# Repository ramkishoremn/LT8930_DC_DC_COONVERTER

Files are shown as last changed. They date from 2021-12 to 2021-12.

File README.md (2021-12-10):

# LT8930_DC_DC_COONVERTER
LT8390 - HIGH EFFICIENCY, SYNCHRONOUS BUCK-BOOST CONTROLLER
This design is based on a LT8390 and has a wider operating voltage range, 6 to 60V input and 1 to 60V output.

In addition, it also has an accurate Under-voltage Lockout with programmable hysteresis, perfect for powering from battery systems.

It also includes output current limiting and Spread Spectrum Frequency Modulation for Low EMI.

This board has been designed to fit into a Hammond 1455C802 Enclosure.

DESIGN CONSIDERATIONS
The LT8390 is a synchronous 4-switch buck-boost DC/DC controller that allows the output voltage to be above, below or equal to the input voltage.

Not only does this provide an extremely flexible DC-DC, it is also ideal for battery operated systems where the battery terminal voltage can fluctuate depending upon the state of charge (SoC). For example, I have been using this converter with a QNAP NAS (Network Attached Storage) to obtain a stable 12.0V (as it directly feeds the HDDs) from a 12V battery that could range anywhere from 10.8V to 14.4V.

The LT8390 operates in current mode and senses the current flowing through the inductor via the inductor sense resistor (R6).

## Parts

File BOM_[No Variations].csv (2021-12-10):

Quantity | Designator | Manufacturer Part Number | Comment | Description | Footprint | LibRef
6 | C1, C2, C3, C4, C5, C6 | EEEFK1J330P | 33uF | Cap Aluminum 33uF 63V 20% (8 X 10.2mm) SMD 250mA 2000h 105 C T/R | PCB-9g04u1co75526zy4kkrl-1 | CMP-7693bfcb6deba954-3
4 | C7, C8, C9, C10 | HMK325C7475MM-PE | 4.7uF | Cap , Midhigh Vol, 1210, 100v, X7s, 4.7uf20% , t&r | CAPC3225X229X50ML20T25 | CMP-cbb5062a85501472-2
2 | C11, C17 | 12101C105KAT2A | 1uF | CAP CER 1UF 100V 10% X7R 1210 | CAPC3225X279X50ML20T25 | CMP-127163-3
3 | C12, C13, C18 | 08055C104JAT2A | 100nF | Capacitor; Ceramic; Cap 0.1 uF; Tol 5%; Vol-Rtg 50 VDC; SMT; 0805; X7R; Tape & Reel | CAPC2013X140X50ML20T25 | CMP-54a29ee556ae8b65-2
1 | C14 | 0805ZD475KAT2A | 4.7uF | CAP CER 4.7UF 10V 10% X5R 0805 | CAPC2013X140X50ML20T25 | CMP-126761-3
1 | C15 | 08055C474JAT2A | 470nF | Multilayer Ceramic Capacitors MLCC - SMD/SMT .47uF 50v 20% Tol. | CAPC2013X140X50ML20T25 | CMP-3555014-4
1 | C16 | 08055C104JAT2A | DNF | Capacitor; Ceramic; Cap 0.1 uF; Tol 5%; Vol-Rtg 50 VDC; SMT; 0805; X7R; Tape & Reel | CAPC2013X140X50ML20T25 | CMP-54a29ee556ae8b65-2
1 | C19 | 08055C103JAT2A | 10nF | cap smd 0805 | CAPC2013X94X50ML20T25 | CMP-16466678-4
1 | D1 | LTST-C170KRKT | Lite-On LTST-C170KRKT | Red 2 x 1.25 x 1.1 mm 130° Water Clear 54 mcd 2 V LED Surface Mount | PCB-5ta9mte2am12bu12jwvi-1 | CMP-1544870-4
1 | F1 | 0154010.DR | 10A | 154 Series Fast-Acting 125 V 10 A OMNI-BLOK® Surface Mount Fuse & Holder | PCB-nlucop3bvobg45y57dd7-1 | CMP-254385-4
1 | J1 | 1757242 | Input | Phoenix 1757242 MSTBA 2.5/ 2-G-5.08 Base Strip/Header 4 Kilo-Volt Surge 320 Volt Rated III/2 12 Amp Green Plug-In | PCB-aknpg75yzj2hq04tmkjt-1 | CMP-0680cf8a1162d947-2
1 | J2 | 1757242 |  | Phoenix 1757242 MSTBA 2.5/ 2-G-5.08 Base Strip/Header 4 Kilo-Volt Surge 320 Volt Rated III/2 12 Amp Green Plug-In | PCB-aknpg75yzj2hq04tmkjt-1 | CMP-0680cf8a1162d947-2
1 | L1 | 7443631000 | 7443631000 | SMD High Current Inductor WE-HCF, L=10.0 µH | WE-HCF-2013 | CMP-913017-2
1 | LP1 | RLP1-200-500 | Bivar RLP1-200-500 | Single Station; 2.8mm; Enhanced Rigid Light Pipe; 5.0mm Elevation; 14.0mm Protrusion | PCB-yzipw91yj2ww1iciyfp2-1 | CMP-b0a0789a751f6f67-3
4 | Q1, Q2, Q3, Q4 | BSC027N06LS5ATMA1 | BSC027N06LS5 | N-Channel OptiMOS5 Power Transistor, 60V VDS, 100A ID, PG-TDSON-8-1 | INF-PG-TDSON-8-1_V | CMP-9dc451c8cc734203-2
1 | R1 | ERJ-MS4HF10MU | 0.01 | Res Metal Alloy 2512 10m Ohm 1% 2W ±75ppm/°C Molded SMD Embossed Carrier T/R | Resistor | CMP-3ffef57a43e1e039-1
1 | R2 | RC0805FR-07182KL | 182K | RES SMD 182K OHM 1% 1/8W 0805 | RESC2013X60X35ML10T20 | CMP-1854500-2
1 | R3 | RC0805FR-07221KL | 221K | Res Thick Film 0805 221K Ohm 1% 0.125W(1/8W) ±100ppm/C Epoxy Pad SMD T/R | RESC2013X60X35ML10T20 | CMP-3600ff19ac10e9c7-1
1 | R4 | RC0805FR-072K8L | 2K8 | RES SMD 2.8K OHM 1% 1/8W 0805 | RESC2013X60X35ML10T20 | CMP-1854595-2
1 | R5 | RC0805FR-0726K1L | 26K1 | Res Thick Film 2.0 x 1.2 mm 26.1K Ohm 1% 0.125W(1/8W) 100ppm/ C Molded SMD Paper T/R | PCB-krsl2knfs9oa082fmtmn-1 | CMP-ab5460010ab47493-2
1 | R6 | ERJ-MS4SF4M0U | 0.004 | Current sense resistor [Panasonic Automotive & Industrial Systems] ERJMS4SF4M0U Current sense resistor | Resistor | CMP-c31e099abffa1cd9-1
1 | R7 | 3296X-1-504LF | Bourns 3296X-1-504LF | Res Cermet Trimmer 500K Ohm 10% 1/2W 25(Elec)Turn 2.19mm (11.05 X 4.83 X 10.03mm) Pin Thru-Hole Tube | PCB-8uuv2uwn1geg2g5qqyha-1 | CMP-793ab03899fca6fd-3
1 | R8 | RC0805FR-0710KL | 10K | RC Series 0805 0.125 W 10 kOhms 1% ±100 ppm/°C SMT Thick Film Chip Resistor | RESC2013X60X35ML10T20 | CMP-1854303-12
3 | R9, R10, R12 | RC0805FR-070RL | 0 | Res Thick Film 0805 0 Ohm Molded SMD Paper T/R | RESC2013X60X35ML10T20 | CMP-1875921-8
1 | R11 | RC0805FR-07330RL | 330 | RC Series 0805 0.125 W 330 Ohms 1% ±100 ppm/°C SMT Thick Film Chip Resistor | RESC2013X60X35ML10T20 | CMP-e8e92397713d372e-2
1 | R13 | RC0805FR-072K2L | 2K2 | Res Thick Film 0805 2.2K Ohm 1% 0.125W(1/8W) 100ppm/ Molded SMD Paper T/R | RESC2013X60X35ML10T20 | CMP-18c6d3bcd80fc701-3
1 | R14 | RC0805FR-07100KL | 100K | Res Thick Film 0805 100K Ohm 1% 0.125W(1/8W} 100ppm/Molded SMD Paper T/R | RESC2013X60X35ML10T20 | CMP-1854318-18
1 | R15 | RC0805FR-070RL | DNF | Res Thick Film 0805 0 Ohm Molded SMD Paper T/R | RESC2013X60X35ML10T20 | CMP-1875921-8
1 | S1 | 200MSP1T2B2M7RE | SW-SPDT-3_B | 200 Series SPDT On-None-On Right Angle Sub-Miniature Toggle Switch | PCB-nfio538mx6iu86i8e1eg-1 | CMP-d175186fcc2b0eb2-2
1 | U1 | LT8390EUFD#PBF | LT8390EUFD#PBF | LT8390 - 60V Synchronous 4-Switch Buck-Boost Controller with Spread Spectrum | LT-UFD-28_M | CMP-ac1b61931e1b73dc-2

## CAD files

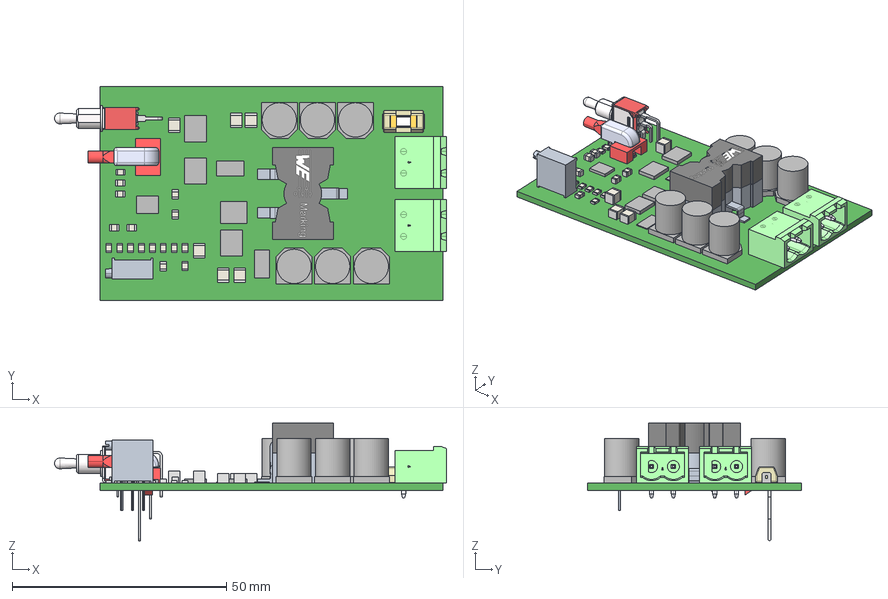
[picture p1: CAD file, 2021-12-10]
STEP_[No Variations].step
91.4 x 50.0 x 27.4 mm
Extruded x 90
Core_base_customer x 2
Core_customer
mstba_2.5-2-g-5.08 x 2
User_Library-OMNI-BLOK_littelfuse
3296X_(1)
200-400-800_MSP_BODY
200-400-800_MSP_BRACKET
200_B2
200_T2
200-400-800_MSP_M7
200-400-800_MSP-DP_M7_SUPPORT
LPR1-200-500-7
RLPH1-1-7

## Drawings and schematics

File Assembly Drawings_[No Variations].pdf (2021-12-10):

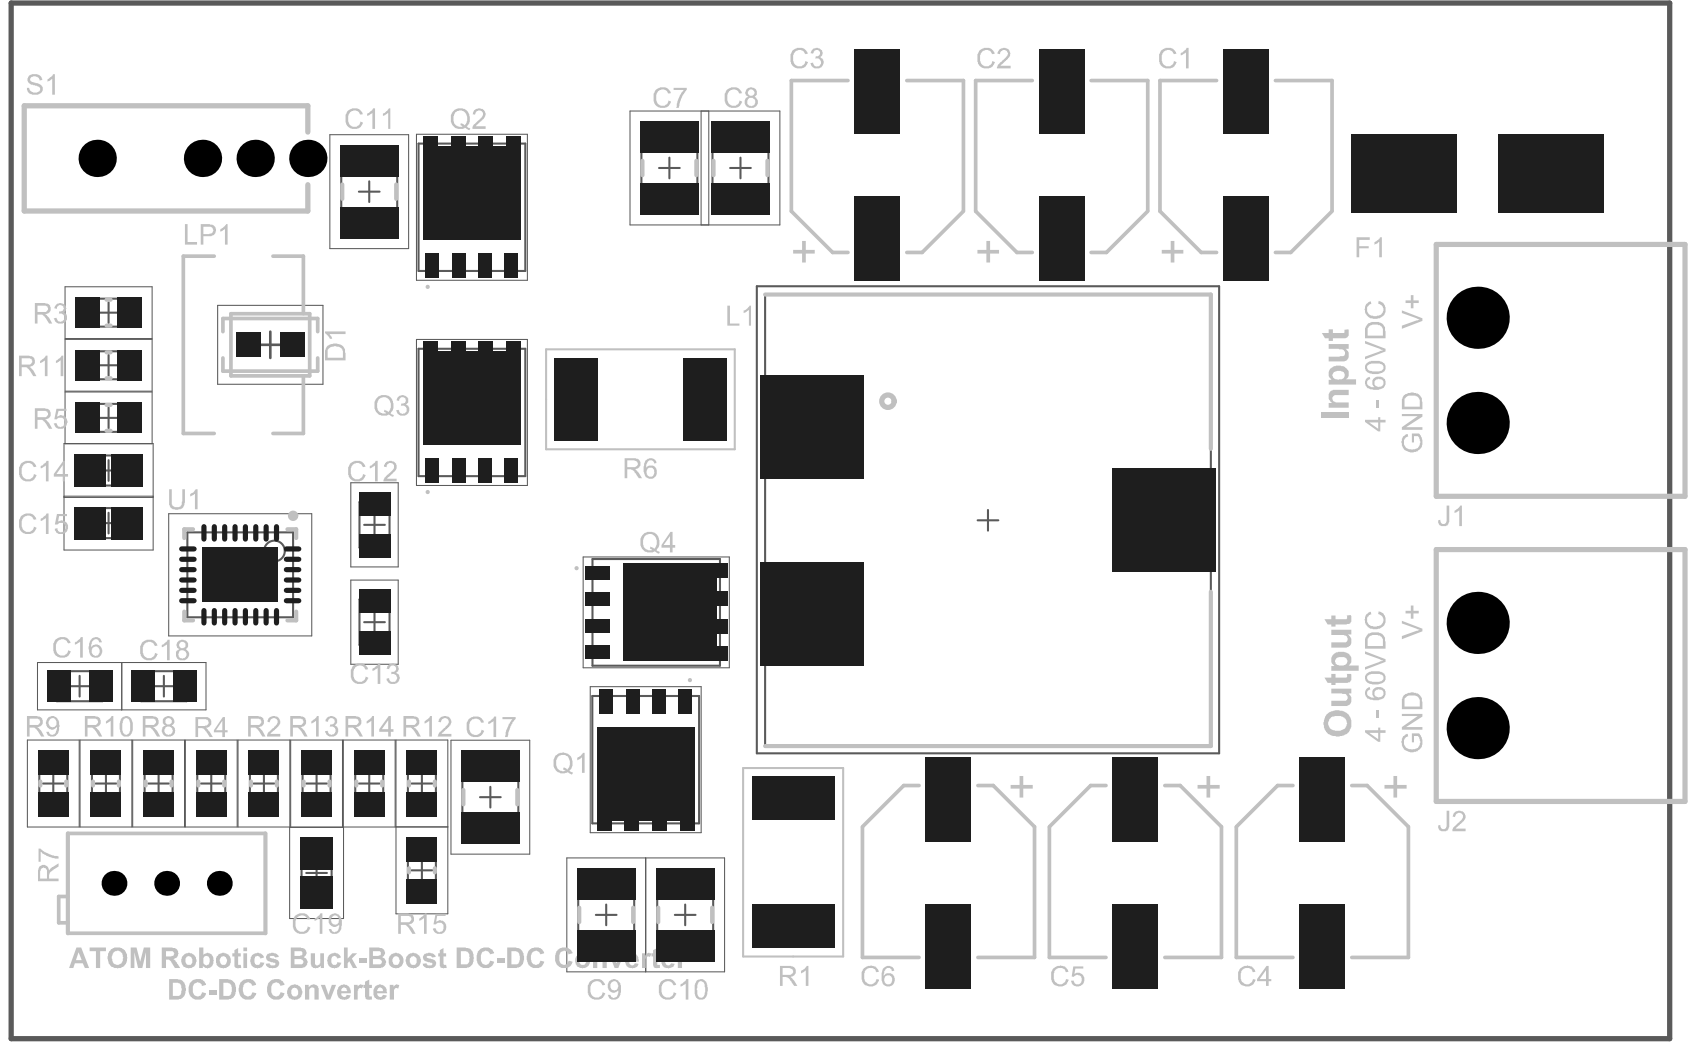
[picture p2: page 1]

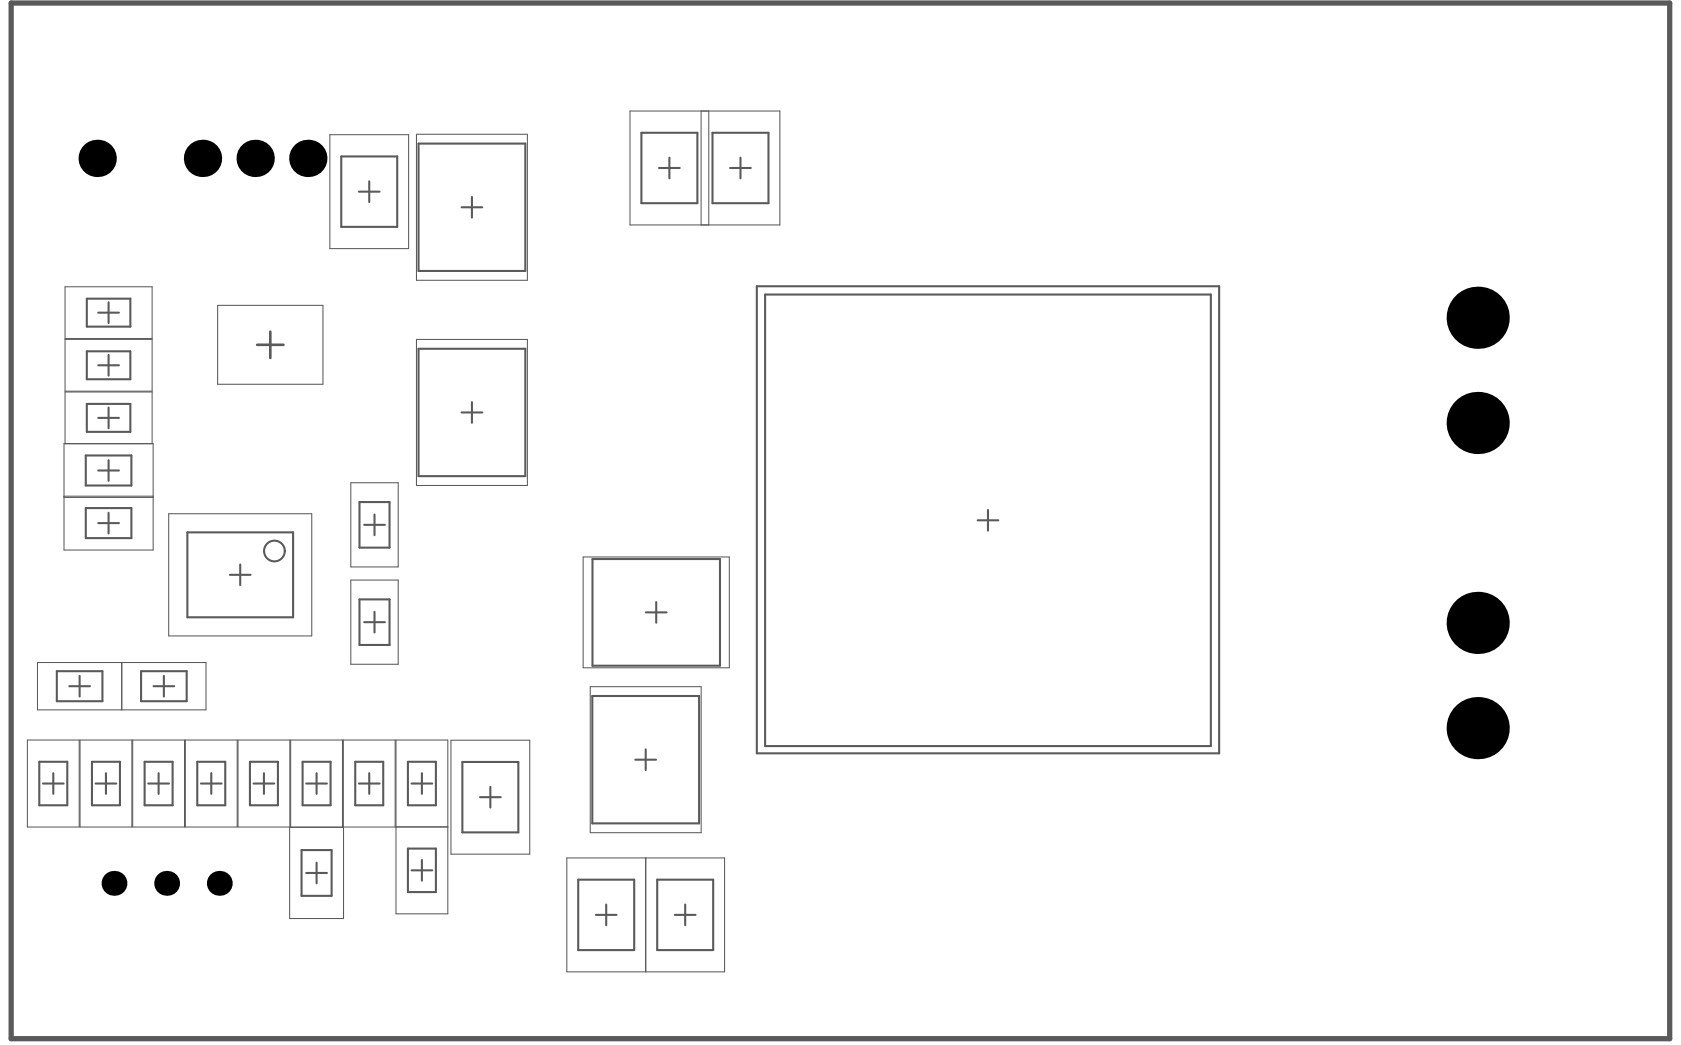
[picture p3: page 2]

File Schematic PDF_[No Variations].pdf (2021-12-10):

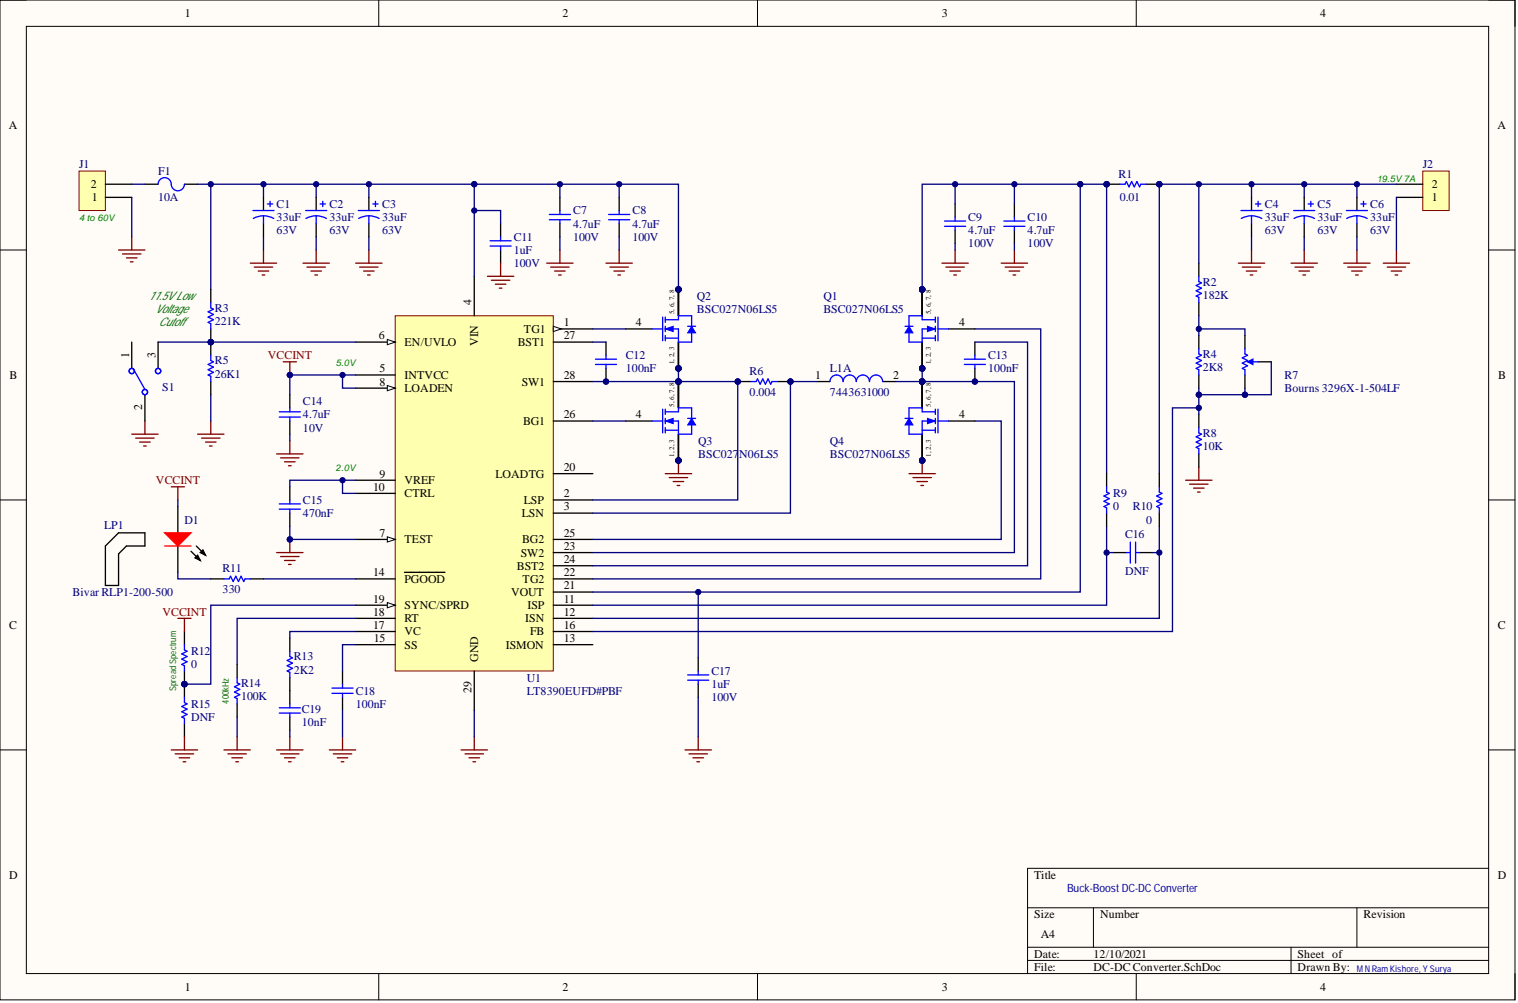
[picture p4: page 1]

1 7 | 1 6
1 | 1 3
